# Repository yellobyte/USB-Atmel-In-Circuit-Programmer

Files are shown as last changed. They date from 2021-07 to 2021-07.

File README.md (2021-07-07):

# USB Atmel in-circuit programmer for AVR controllers #

This is yet another version of Thomas Fischl's [USBasp](https://www.fischl.de/usbasp/) device, an USB in-circuit programmer for Atmel AVR controllers.

The idea to put the USBasp into a nice little enclosure from [Fischer Elektronik](https://www.fischerelektronik.de) (Enclosure Model: FR 55 25 80 ME) I got from [Ulrich Radig's](https://www.ulrichradig.de/home/index.php/avr/usb-avr-prog) website.

What I really missed were some buttons to quickly select/deselect the two very helpful features "Slow Programming Speed" and "Powering Target" if needed. Further I missed a small 6-pin box header with 1.27mm pitch for connections to small targets that don't have enough space on their PCB to fit a big 10-pin/6-pin box header with 2.54mm pitch (20.3mm x 8.9mm resp. 15.22mm x 8.9mm in size).

Therefore I integrated those little goodies and that's the result as shown below.

### Front side with 2 Buttons and USB Socket: ###
  
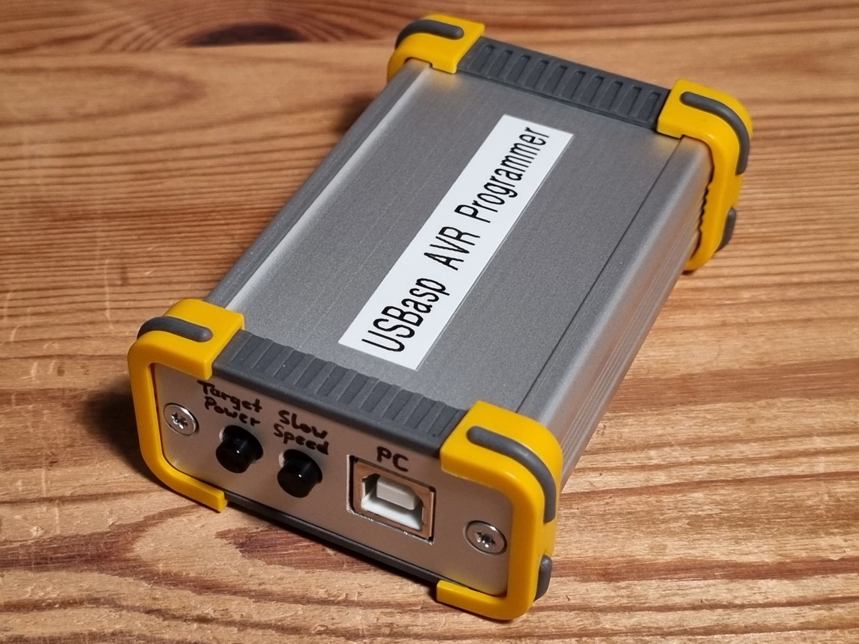
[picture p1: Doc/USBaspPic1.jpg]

  
### Rear side with box headers (1.27mm/2.54mm pitch) and LEDs: ###
  
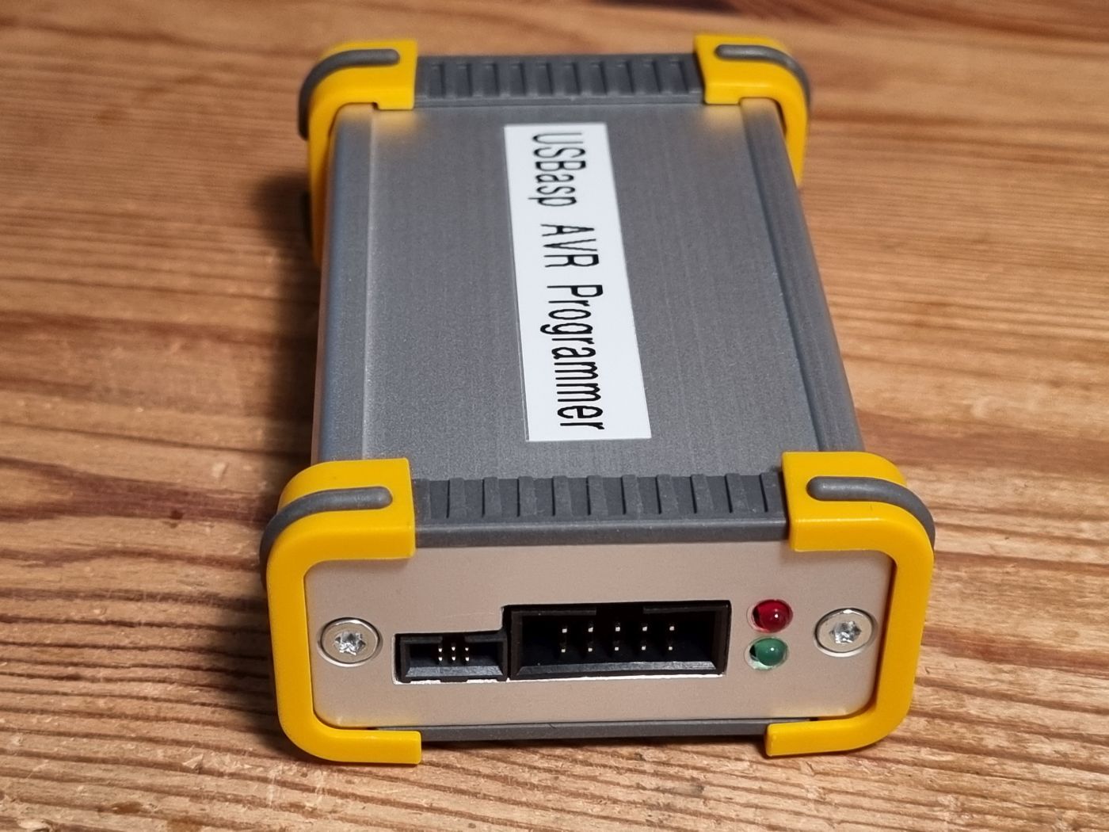
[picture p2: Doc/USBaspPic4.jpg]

  
### Flashing a target via small box header: ###
  
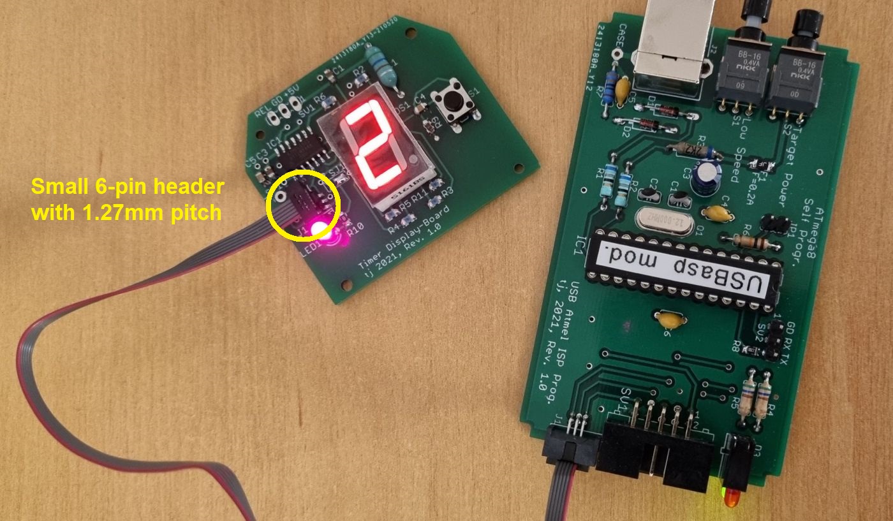
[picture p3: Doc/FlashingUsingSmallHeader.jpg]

  
## Some technical infos ##

The PCB is very similar to the one Ulrich Radig created for the same enclosure. As mentioned before, I additionally added 2 subminiature push buttons and a small Samtec 6-pin box header with 1.27mm pitch.

Wiring of both headers (6-pin & 10-pin) follow the standards for AVR in-system programming. If you are interested and want to dive into detail, have a look at paragraph "In-System Programming interface" [here](https://www.ladyada.net/learn/avr/programming.html).

The software on the Atmega8 is original USBasp code from Thomas Fischl.

Button S2 is for powering the target. The 5V power supply to the target is fused with a 0.2A self recovering fuse. If the target needs more current it must be powered seperately.
  
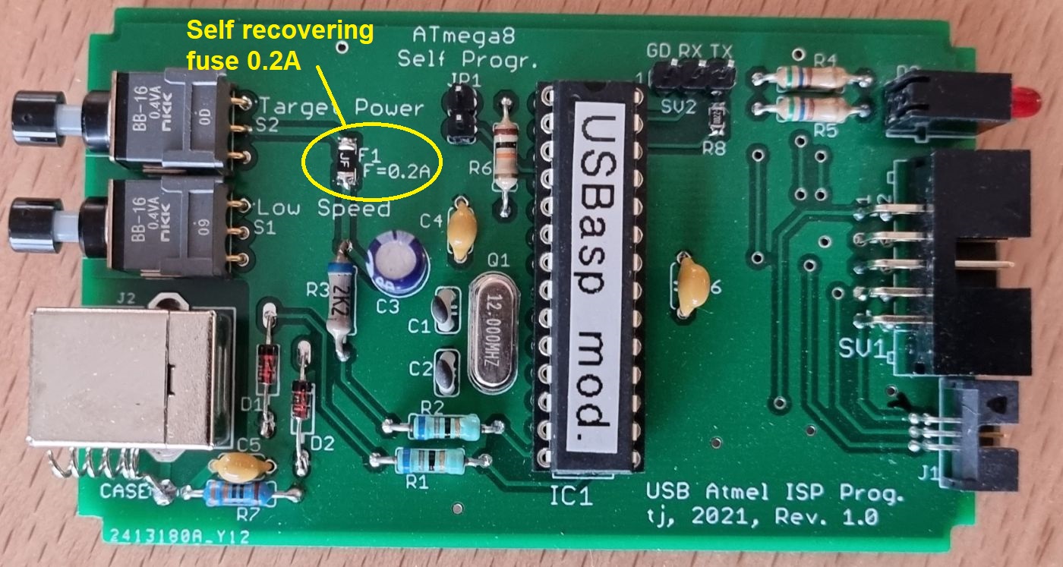
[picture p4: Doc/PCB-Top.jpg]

  
Button S1 is for selecting a slow target programming speed. This is very helpful if one tries to flash new AVR controller chips for the very first time. Some AVR controllers, when delivered, use by default an internal clock generator running on a low frequency and therefore won't answer when addressed by an USBasp with normal programming speed, because it is simply too fast for them. That can be a real trap for AVR novices...

Jumper JP1 is only (temporarily) shorted when the Atmega8 in the programmer must be programmed itself. It should be open by default.

The little spring (shown in the lower left corner in the picture above) connects the USB socket shield properly with the aluminium enclosure. The enclosure itself (and therefore the USB cable shield) is only connected to GND of the circuitry via R7||C5 ! 

The 2 subminiature push buttons (Manufacturer "NKK Switches", Model "BB16AH-FA") and the little box header with 1.27mm pitch (Manufacturer Samtec, Model "SHF-103-01-L-D-TH") are normally available from Mouser/Farnell/etc.

## PCB Files ##

You find the schematic, board pictures and the Gerber production files (rev 1.1) in folder [**PCB**](https://github.com/yellobyte/USB-Atmel-In-Circuit-Programmer/blob/main/PCB). I zipped all necessary Gerber files into file "USBasp Gerber Files Rev1.1.zip".  

All you need is to send the zip file to a decent PCB manufacturer, pay and wait for the PCB(s) to arrive at your doorstep.

Remark:  
The pictures in folder [**Doc**](https://github.com/yellobyte/USB-Atmel-In-Circuit-Programmer/blob/main/Doc) still show board revision 1.0.  Revision 1.1 is almost identical and contains only cosmetic changes.

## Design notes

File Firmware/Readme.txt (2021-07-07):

This original Thomas Fischl USBasp firmware can be found under:    
		https://www.fischl.de/usbasp/

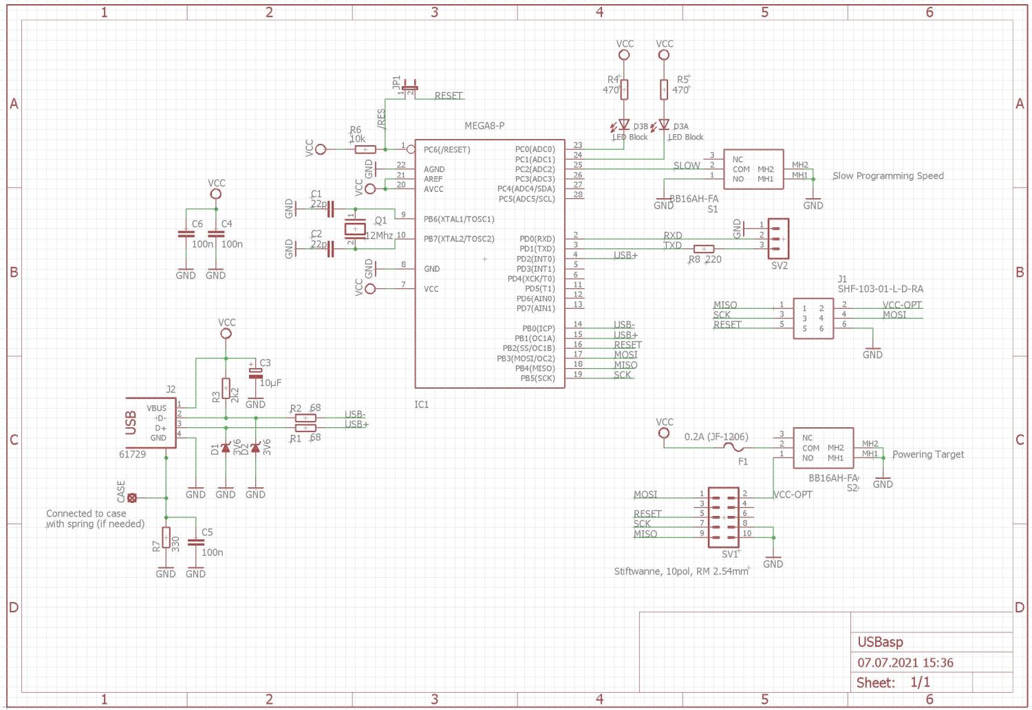
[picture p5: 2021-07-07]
PCB/Schematic.JPG

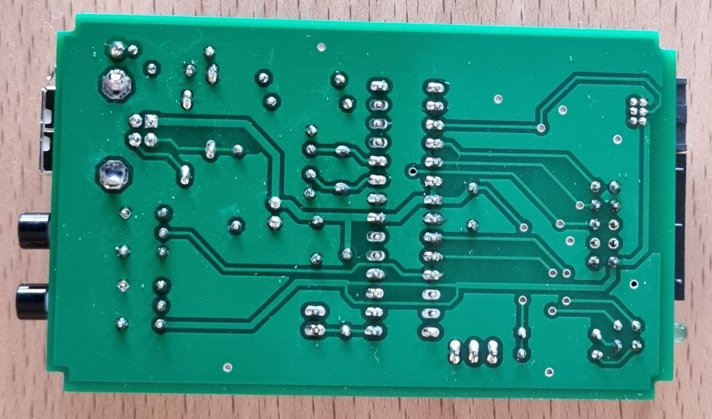
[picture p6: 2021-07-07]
Doc/PCB-Bottom.jpg

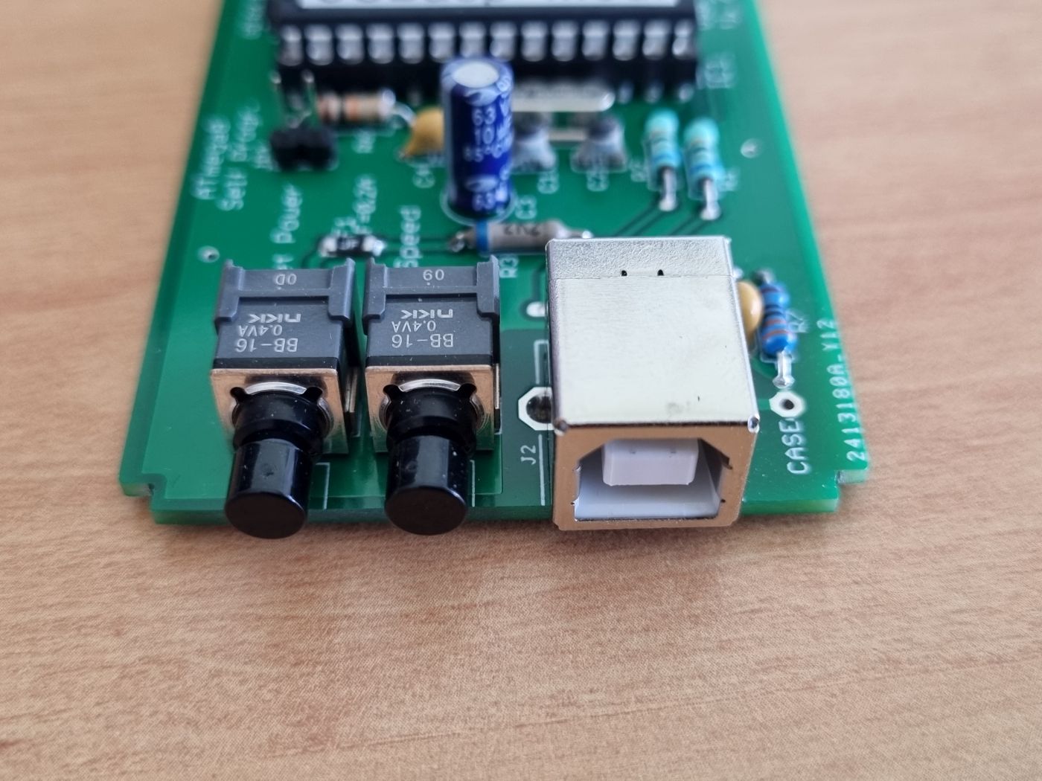
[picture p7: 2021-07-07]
Doc/USB+Switches.jpg

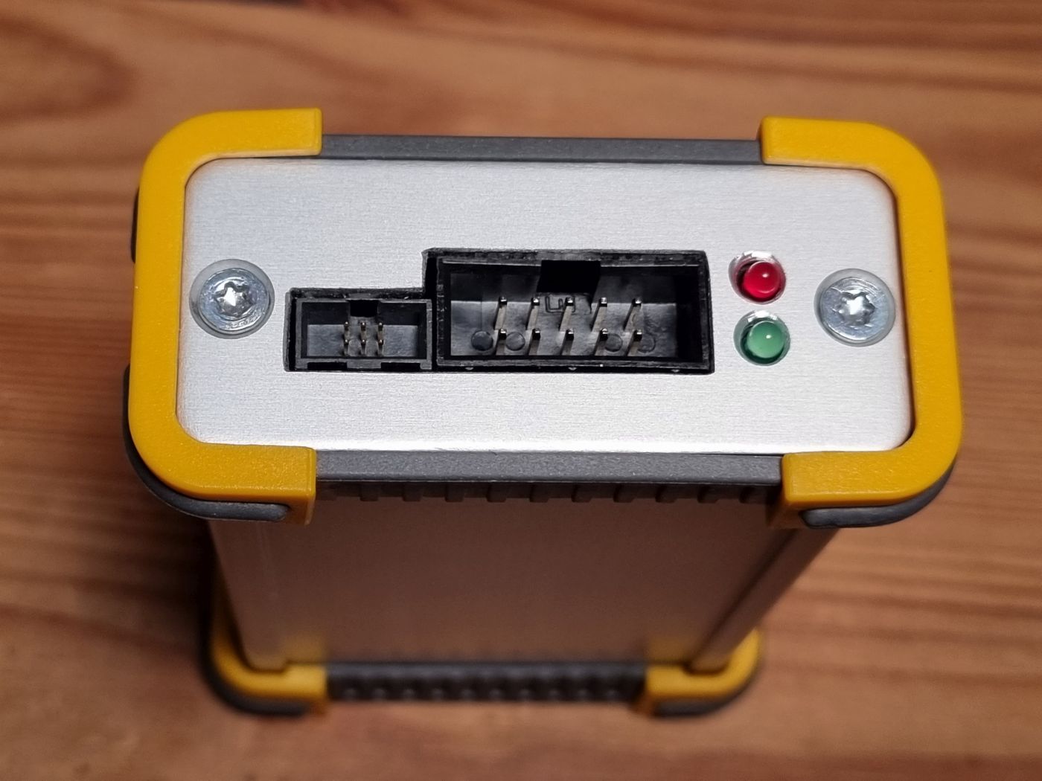
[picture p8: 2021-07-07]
Doc/USBaspPic6.jpg

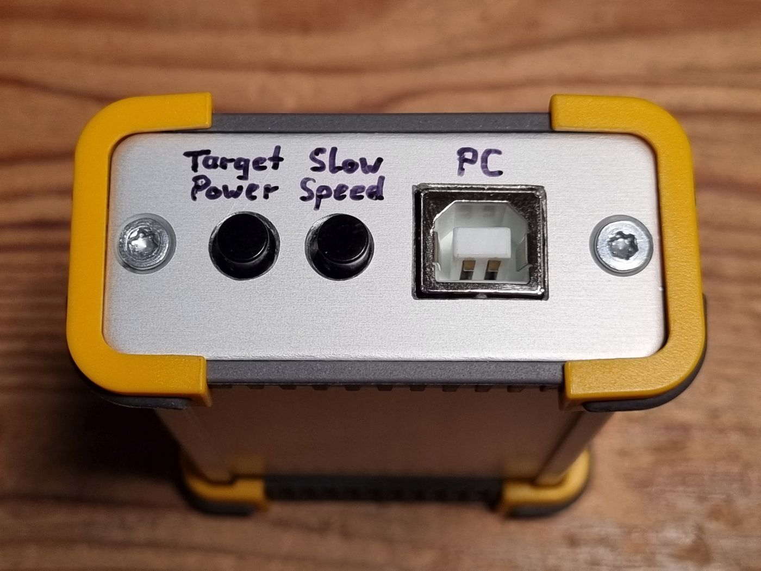
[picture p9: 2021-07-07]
Doc/USBaspPic5.jpg

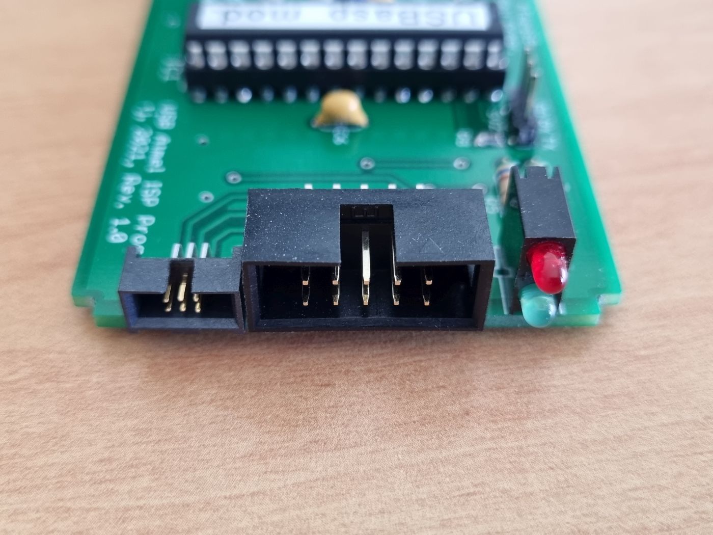
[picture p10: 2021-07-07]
Doc/Sockets+LEDs.jpg

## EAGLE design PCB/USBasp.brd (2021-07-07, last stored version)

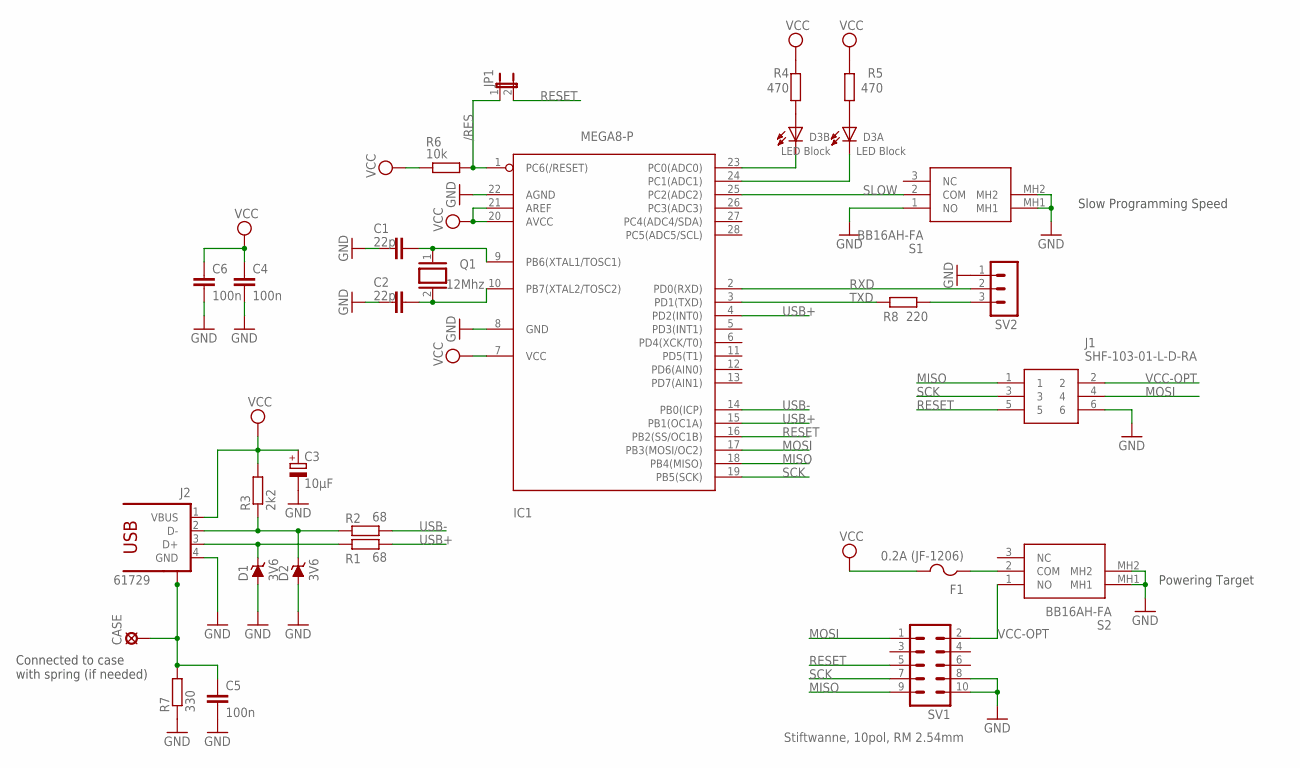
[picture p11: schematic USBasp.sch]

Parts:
C1, C2: 22p; C025-024X044
C3: 10µF; E2,5-6
C4, C5, C6: 100n; C050-024X044
CASE: LSP10
D1, D2: 3V6; DO35Z10
D3: LED Block; 1801_PINS_SWAPPED
F1: 0.2A (JF-1206); R1206
IC1: MEGA8-P; DIL28-3
J1: SHF-103-01-L-D-RA; SHF10301LDRA
J2: 61729
JP1: JP1E; JP1
Q1: 12Mhz; QS
R1, R2: 68; 0207/10
R3: 2k2; 0207/10
R4, R5: 470; 0207/10
R6: 10k; 0207/10
R7: 330; 0207/10
R8: 220; R0805
S1, S2: BB16AH-FA; BB16AHFA
SV1: Stiftwanne, 10pol, RM 2.54mm; ML10L
SV2: MA03-1

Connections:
/RES: IC1.1 (PC6(/RESET)), JP1.1, R6.2
GND: C1.1, C2.1, C3.-, C4.2, C5.2, C6.2, D1.A, D2.A, IC1.8 (GND), IC1.22 (AGND), J1.6, J2.4 (GND), R7.1, S1.1 (NO), S1.MH1, S1.MH2, S2.MH1, S2.MH2, SV1.8, SV1.10, SV2.1
MISO: IC1.18 (PB4(MISO)), J1.1, SV1.9
MOSI: IC1.17 (PB3(MOSI/OC2)), J1.4, SV1.1
unnamed: D3.A1 (A), R4.1
unnamed: C5.1, CASE.MP, J2.S1, J2.S2, R7.2
unnamed: C1.2, IC1.9 (PB6(XTAL1/TOSC1)), Q1.1
unnamed: C2.2, IC1.10 (PB7(XTAL2/TOSC2)), Q1.2
unnamed: D1.C, J2.3 (D+), R1.1
unnamed: D2.C, J2.2 (D-), R2.1, R3.1
unnamed: D3.A, R5.1
unnamed: D3.K1 (K), IC1.23 (PC0(ADC0))
unnamed: D3.K, IC1.24 (PC1(ADC1))
unnamed: F1.1, S2.2 (COM)
unnamed: R8.2, SV2.3
RESET: IC1.16 (PB2(SS/OC1B)), J1.5, JP1.2, SV1.5
RXD: IC1.2 (PD0(RXD)), SV2.2
SCK: IC1.19 (PB5(SCK)), J1.3, SV1.7
SLOW: IC1.25 (PC2(ADC2)), S1.2 (COM)
TXD: IC1.3 (PD1(TXD)), R8.1
USB+: IC1.4 (PD2(INT0)), IC1.15 (PB1(OC1A)), R1.2
USB-: IC1.14 (PB0(ICP)), R2.2
VCC: C3.+, C4.1, C6.1, F1.2, IC1.7 (VCC), IC1.20 (AVCC), IC1.21 (AREF), J2.1 (VBUS), R3.2, R4.2, R5.2, R6.1
VCC-OPT: J1.2, S2.1 (NO), SV1.2

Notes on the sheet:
Powering Target
Slow Programming Speed
Connected to case with spring (if needed)

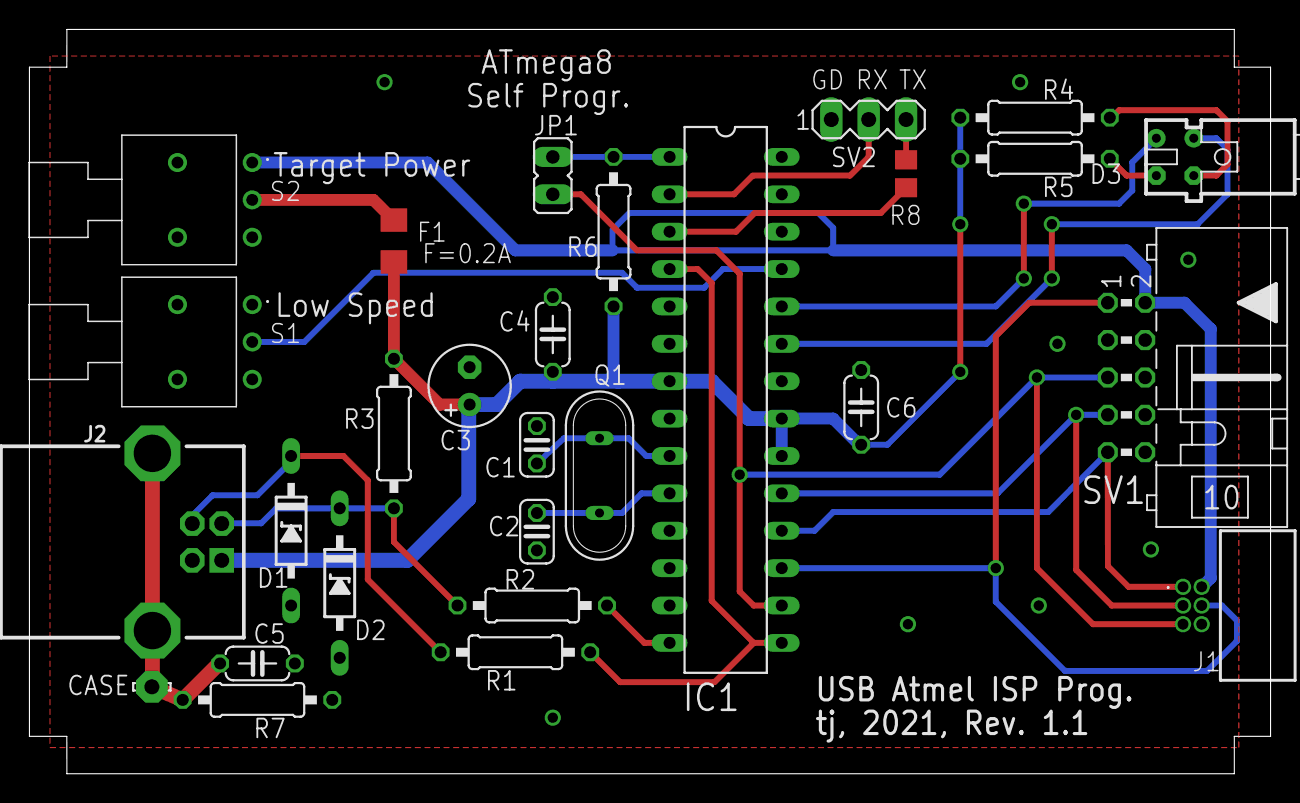
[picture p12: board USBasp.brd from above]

Board: 2 copper layers, 84.3 x 50.6 mm, 28 parts (0 on the bottom side), 24 nets.

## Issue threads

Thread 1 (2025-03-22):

BOM file

ChenW12, 2025-03-22:
Hi,

First of all, I think the design is awesome and I'm trying to make one for my own. Thank you for your contribution. I didn't see the BOM file, and I'm wondering would it be possible to have one so it's easier to buy the parts online.

Thank you again.

yellobyte, 2025-03-22:
Hi there,
I still have some spare PCBs lying around. If you are keen to get one drop me an eMail to yellobyte@bluewin.ch containing your postal address. I even can supply some of the components (resistors, caps, etc.) so you wouldn't need a complete BOM file.
I actually have soldered all components onto the PCB myself. I would have to create a BOM if you really insist. :-)
Cheers yb

ChenW12, 2025-03-22:
It's very kind of you, but I'm in China so it may not be worth to send the parts from Switzerland, and I'm learning the electronics stuff so I would like to take a closer look at the PCB design myself. Please keep the spare PCBs for other people who are interested in this design :-). Yes please upload a BOM file. Thank you.

yellobyte, 2025-03-22:
Ok, thats fine. As I'm out of town for a week I will create a BOM and add it to the repo when I get home. Cheers yb

yellobyte, 2025-04-05:
Sorry for the delay. BOM file is now available in folder Doc. Regards yb

yellobyte, 2025-04-27:
FYI: USBasp-BOM.zip now contains USBasp-BOM.**xlsx** and USBasp-BOM.**csv**.

Closed 2025-04-05.

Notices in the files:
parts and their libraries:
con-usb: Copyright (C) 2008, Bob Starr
